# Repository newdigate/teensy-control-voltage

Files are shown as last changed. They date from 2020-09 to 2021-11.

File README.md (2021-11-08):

# teensy control voltage analog computer shield 








**open source [hardware](hardware) ~~and [software](software)~~ for a [teensy 4.1](https://www.pjrc.com/store/teensy40.html "teensy 4.1 board") eurorack control voltage shield** 

extend a [teensy 4.1](https://www.pjrc.com/store/teensy40.html "teensy 4.1 board") with peripherals to interface with eurorack modular equipment. 

 




## specifications
* **microcontrollers:** 
  * 600 Mhz ARM cortex m7 ( [teensy 4.1 board](https://www.pjrc.com/store/teensy41.html "teensy 4.1 board") )
* **display:** ST7735 128x128 16bit-color tft display
* **breakouts:** 
  * microSD card socket, 
  * USB host/device, 
  * midi in/out, 
  * 1 x encoders w/switch
* **panel:** 14HP aluminium panel mounted for eurorack case
* **programability**: 
  * write arduino compatible c/c++ firmware & program using arduino/teensyduino
  * arm gnu toolchain [downloads](https://developer.arm.com/tools-and-software/open-source-software/developer-tools/gnu-toolchain/gnu-rm/downloads)
  * teensy [audio library](https://www.pjrc.com/teensy/gui/)

## MIT open source license
* MIT license unless otherwise specified on a per file basis.

## Open source software stack
* All [schematics](hardware/CIRCUITS.md) and boards are created using [Kicad](http://kicad.org/) 
* All mechanical designs are created using [FreeCAD](https://github.com/FreeCAD/FreeCAD)
* Some images have been rendered using [Blender 2.81](https://www.blender.org/)

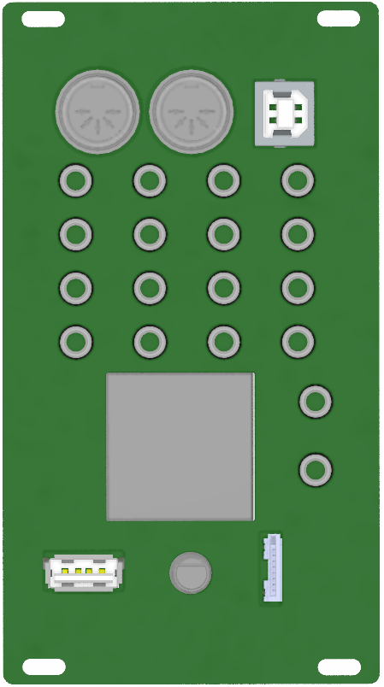
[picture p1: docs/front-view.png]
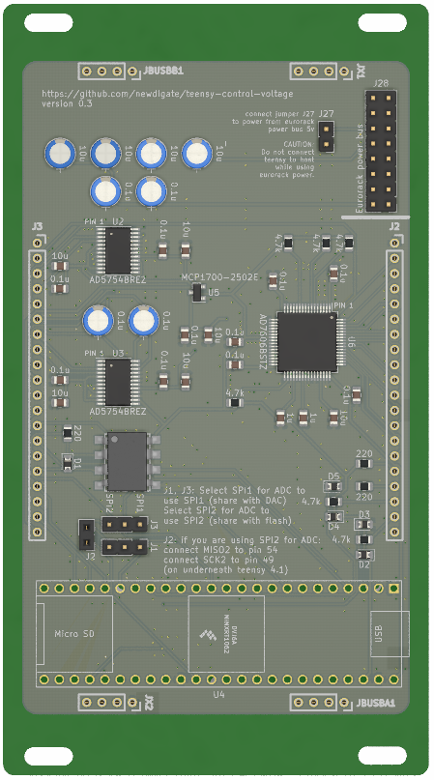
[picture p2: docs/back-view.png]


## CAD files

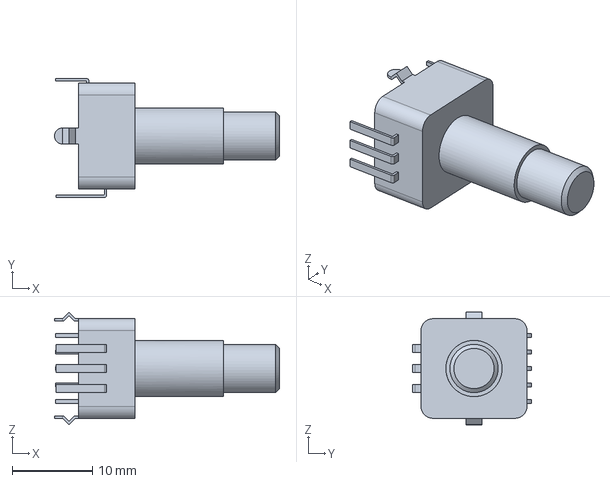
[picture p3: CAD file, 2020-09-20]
hardware/boards/3d/Bourns PEL12T4225S-S1024.step
28.0 x 14.8 x 14.0 mm

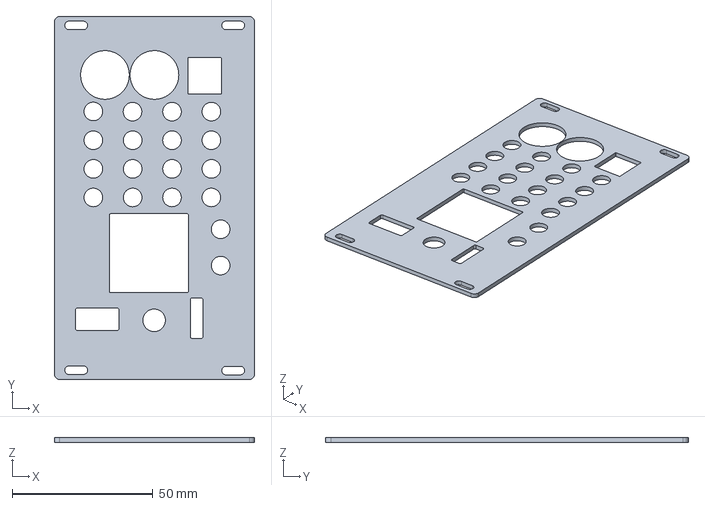
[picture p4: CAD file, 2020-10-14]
hardware/front-panel/front-panel.step
71.1 x 128.9 x 1.60 mm

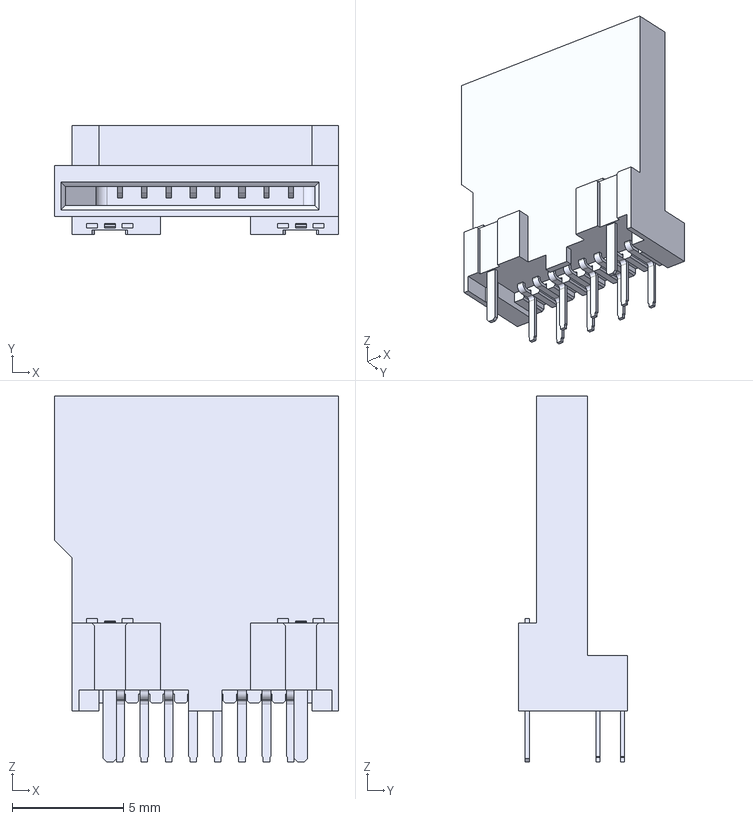
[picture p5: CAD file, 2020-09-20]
hardware/boards/3d/Yamaichi - PJS008U-3000-0.step
12.8 x 4.90 x 16.5 mm

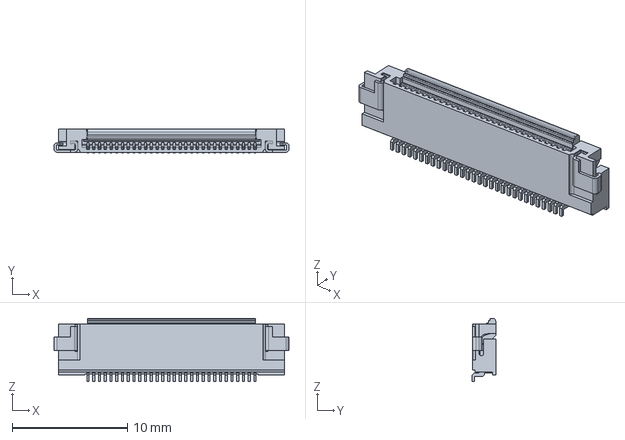
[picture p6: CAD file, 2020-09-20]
hardware/boards/3d/Molex-52892-3033.step
20.4 x 2.04 x 5.50 mm

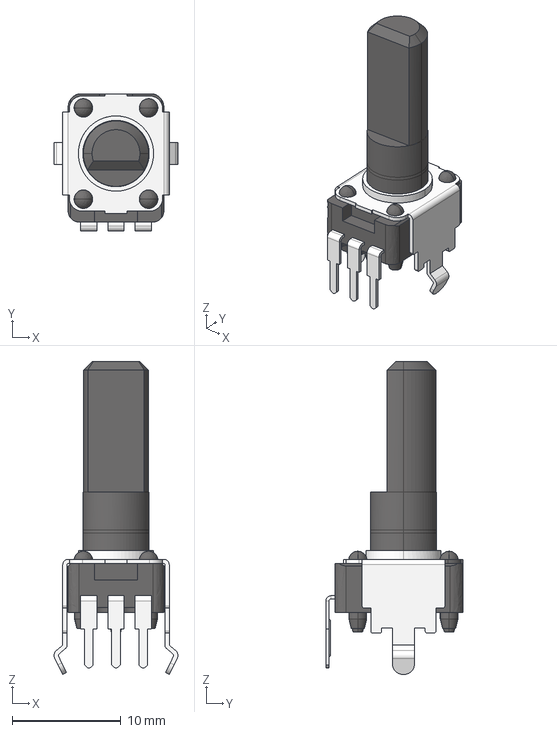
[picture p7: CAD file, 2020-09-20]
hardware/boards/3d/RK09K1130AH1.STEP
11.4 x 12.7 x 28.8 mm

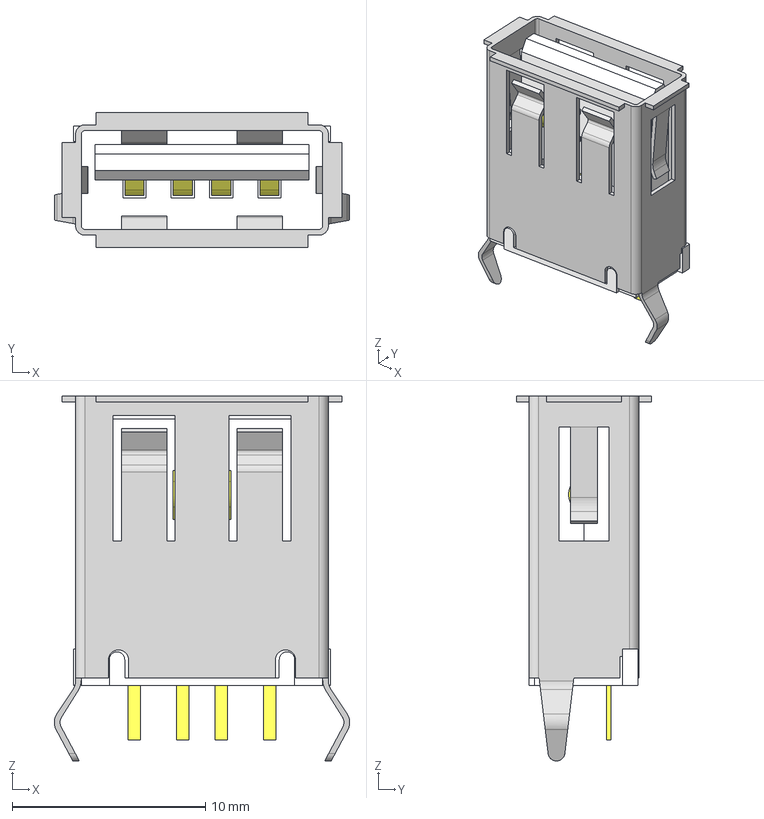
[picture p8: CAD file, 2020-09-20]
hardware/boards/3d/USB-A-S-S-W-VT.stp
15.3 x 7.00 x 18.9 mm
_USB-A-S-VT_S
_USB-A-S-W-VT_B
_USB-A-S-VT_P

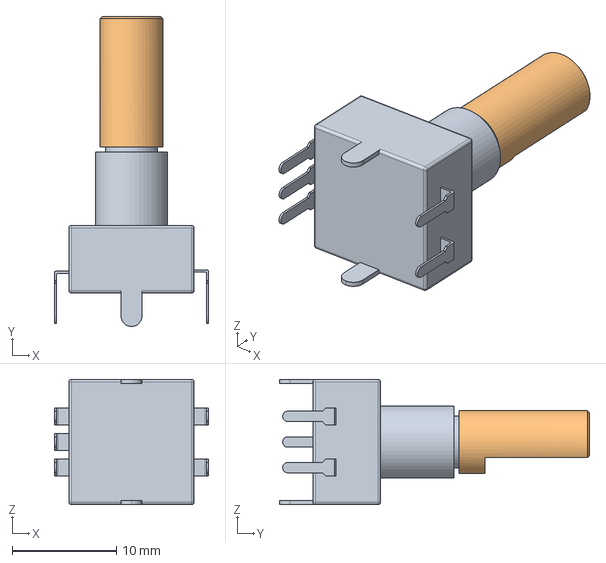
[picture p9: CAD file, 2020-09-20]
hardware/boards/3d/RotaryEncoder_Alps_EC11E-Switch_Vertical_H20mm.step
14.8 x 29.7 x 12.0 mm

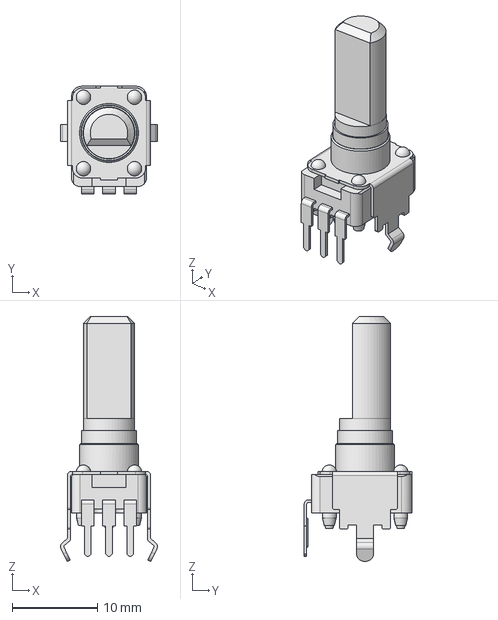
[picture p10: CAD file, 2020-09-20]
hardware/boards/3d/Panasonic_EVU-F2MFL3D14.step
11.4 x 12.7 x 28.8 mm

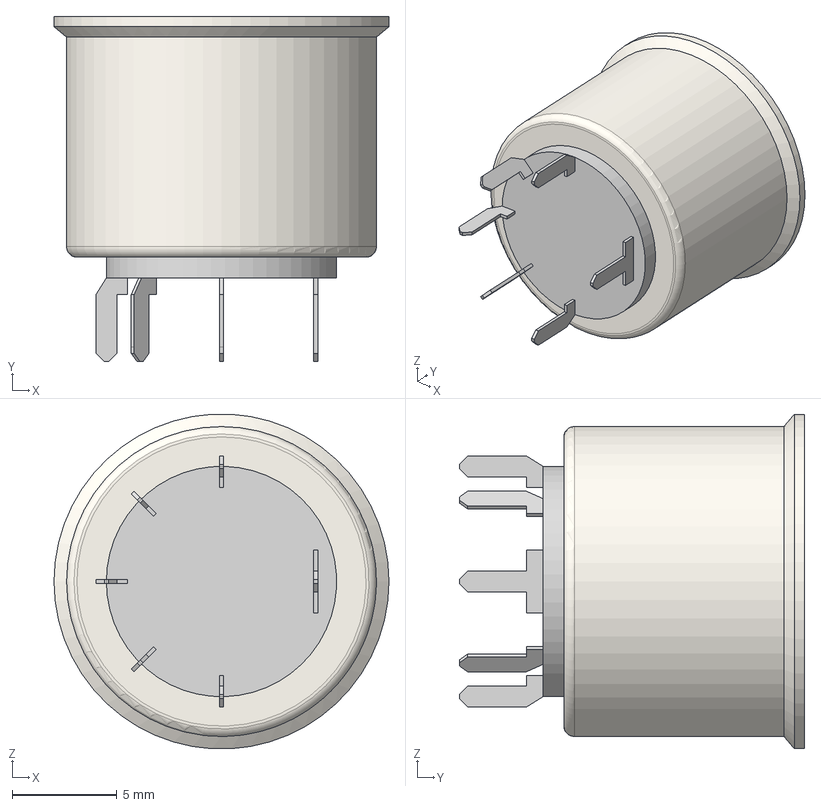
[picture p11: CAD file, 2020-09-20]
hardware/boards/3d/MIDI DIN 5 v7.step
16.0 x 16.5 x 16.0 mm

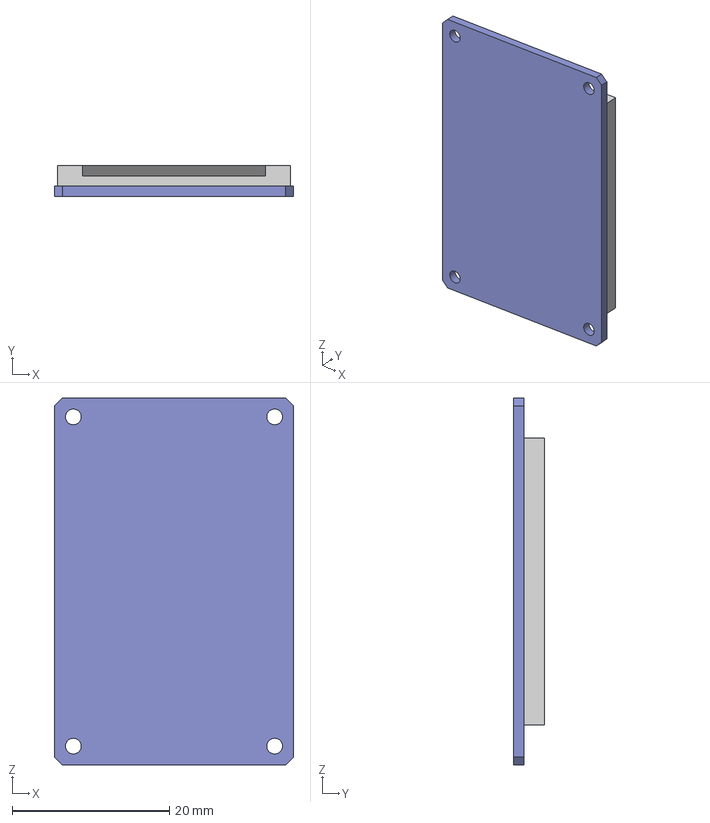
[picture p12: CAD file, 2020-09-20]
hardware/boards/3d/ili7735 v6.step
30.4 x 3.90 x 46.6 mm

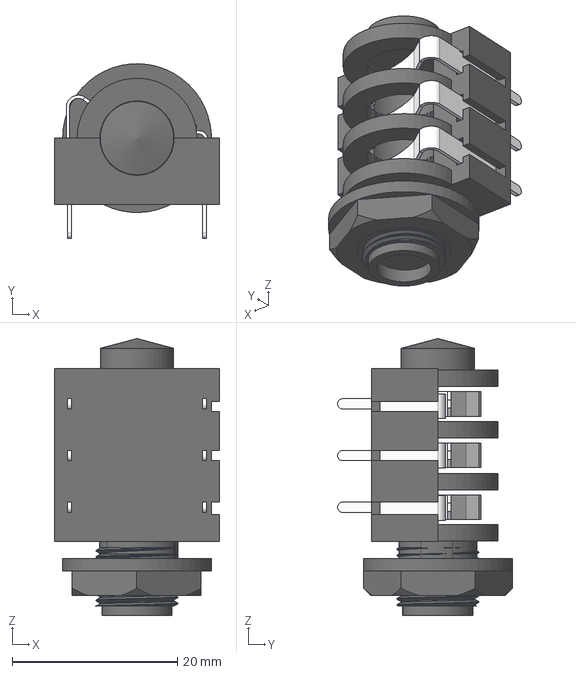
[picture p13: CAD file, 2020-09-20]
hardware/boards/3d/ACJS-PH v28.step
20.0 x 21.1 x 33.5 mm
JackConnector-female-6.35-entrance-threaded
nut

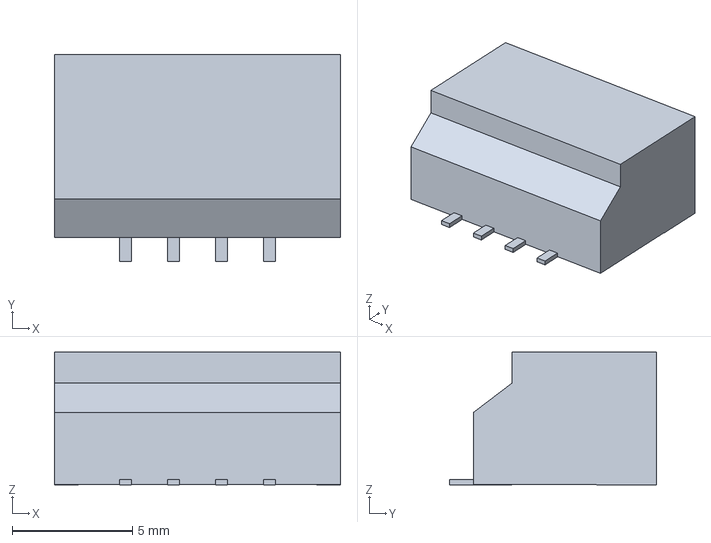
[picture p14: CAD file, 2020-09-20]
hardware/boards/3d/conn_JST_S4B-PH-SM4-TB(LF)(SN).step
11.9 x 8.60 x 5.52 mm

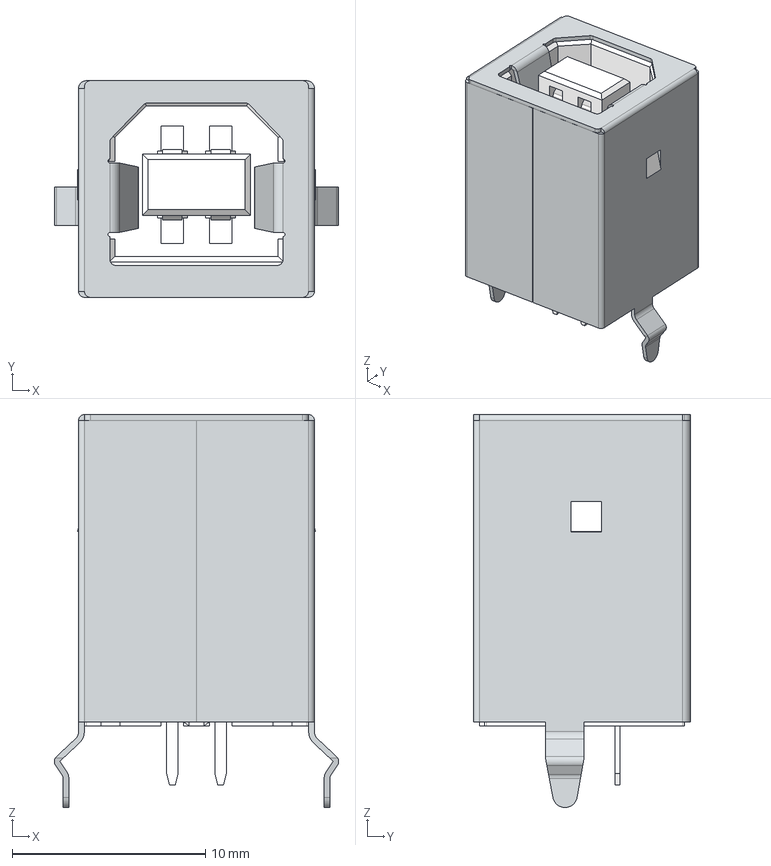
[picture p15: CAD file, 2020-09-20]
hardware/boards/3d/Conn_Wurth Electronics_61400413321.step
14.7 x 11.2 x 20.3 mm

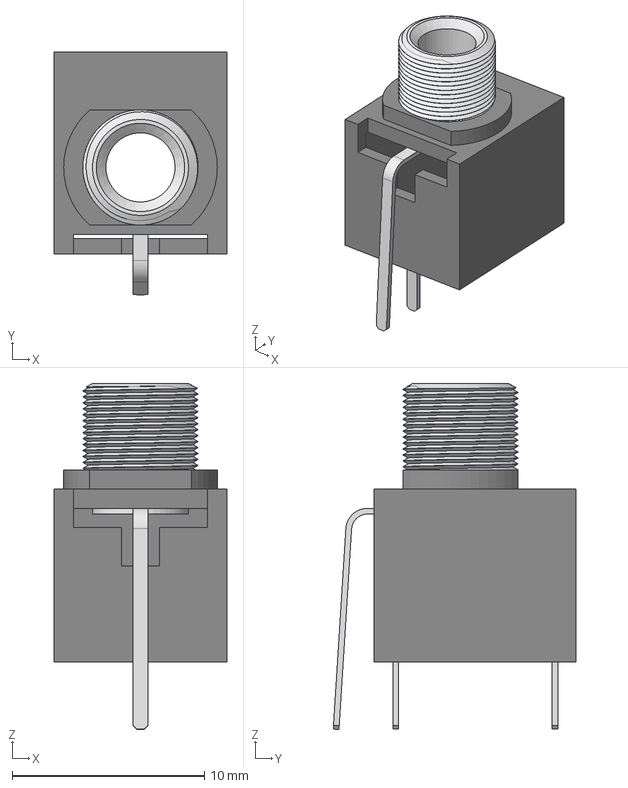
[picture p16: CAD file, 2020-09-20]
hardware/boards/3d/PJ301M-12 Thonkiconn v0.2.stp
9.00 x 12.6 x 18.0 mm

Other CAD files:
hardware/boards/3d/Bourns PEL12T4225S-S1024-white.step
hardware/boards/3d/ACJS-MV35-5.step
hardware/boards/3d/ZX62-AB-5PA.stp
hardware/boards/3d/User Library-8-pin-DIP_GW_HCPL-4200-300E.STEP
hardware/boards/3d/1734592-8.stp
hardware/boards/3d/CS42448-CQZ.step
hardware/boards/3d/HFW8R-1STE1LF.stp

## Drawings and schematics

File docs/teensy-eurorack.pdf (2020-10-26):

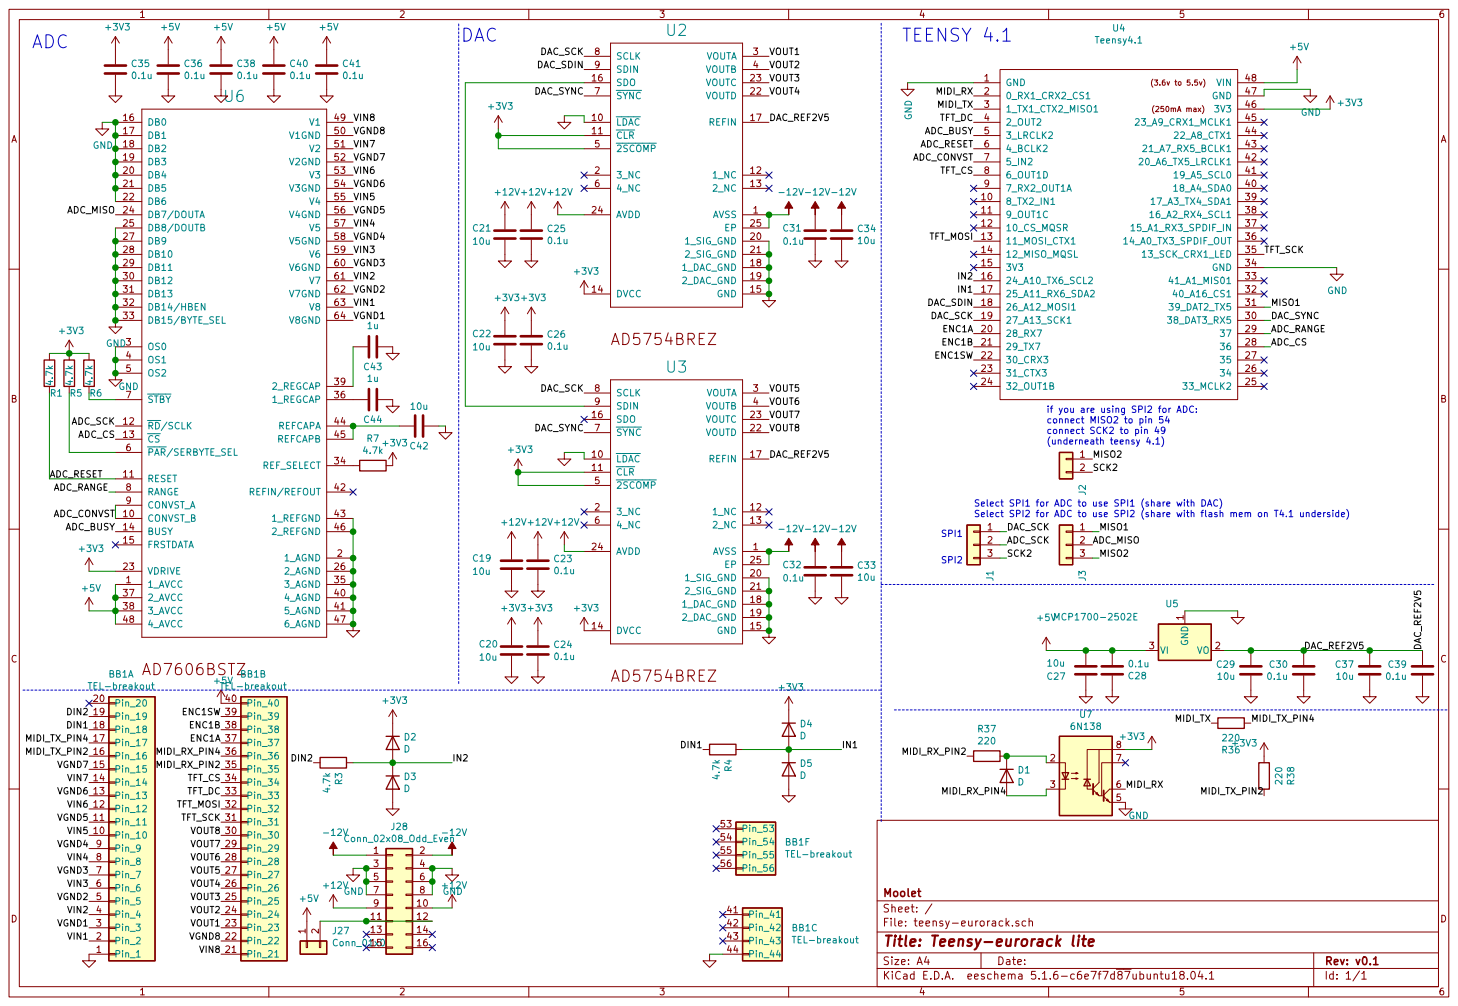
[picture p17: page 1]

if you are using SPI2 for ADC:
connect MISO2 to pin 54
connect SCK2 to pin 49
(underneath teensy 4.1)

Select SPI1 for ADC to use SPI1 (share with DAC)

Select SPI2 for ADC to use SPI2 (share with flash mem on T4.1 underside) SPI1 SPI2

File: teensy-eurorack.sch Sheet: / Moolet

Id: 1/1 Title: Teensy-eurorack lite

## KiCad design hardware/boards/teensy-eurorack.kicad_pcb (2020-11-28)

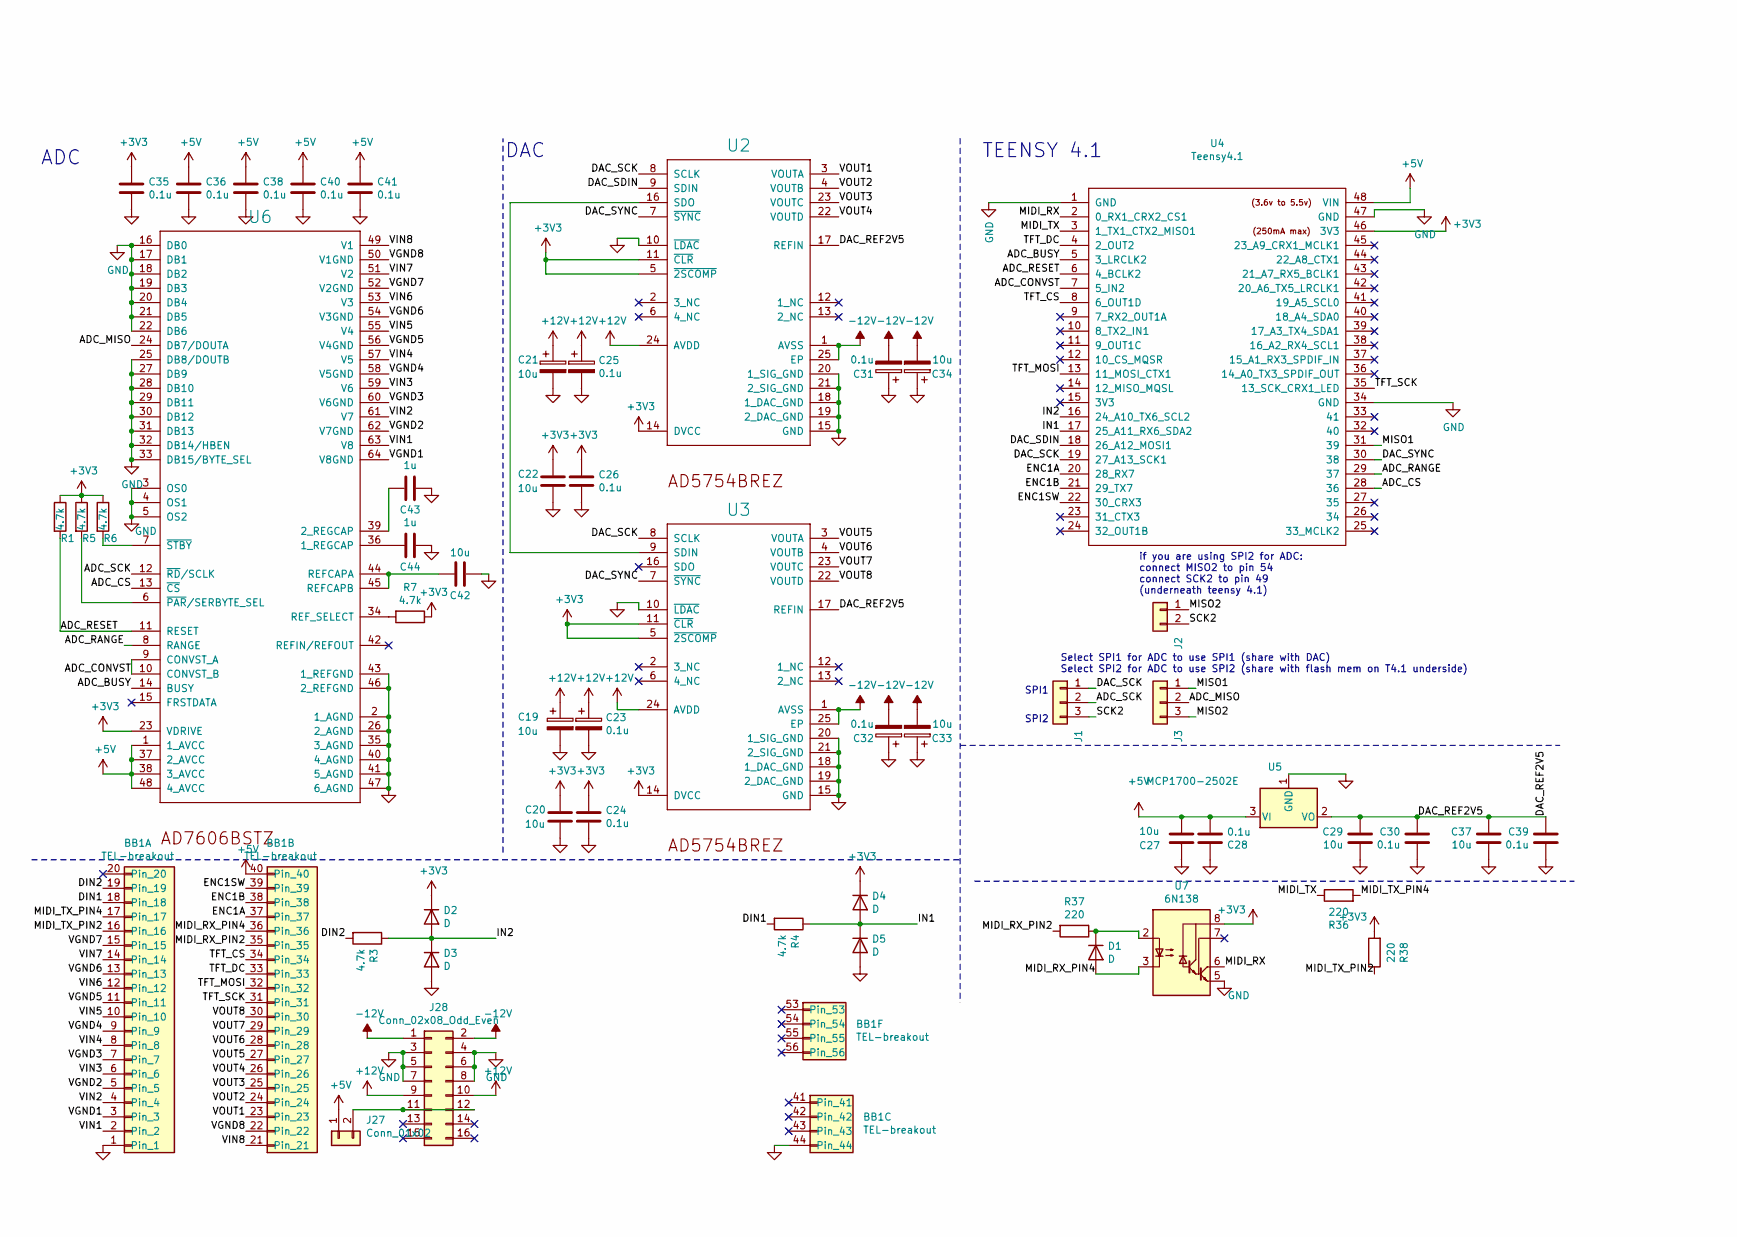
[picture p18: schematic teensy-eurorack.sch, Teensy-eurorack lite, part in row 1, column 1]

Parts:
BB1: TEL-breakout; TElite-breakout-board
C19, C21, C33, C34: 10u; CP_Radial_D5.0mm_P2.00mm
C20, C22, C27, C29, C37, C42: 10u; C_0805_2012Metric
C23, C25, C31, C32: 0.1u; CP_Radial_D5.0mm_P2.00mm
C24, C26, C28, C30, C35, C36, C38, C39, C40, C41: 0.1u; C_0805_2012Metric
C43, C44: 1u; C_0805_2012Metric
D1, D2, D3, D4, D5: D; D_0805_2012Metric
J1, J3: Conn_01x03; Pin_Header_Straight_1x03_Pitch2.54mm
J2: Conn_01x02; Pin_Header_Straight_1x02_Pitch2.54mm
J27: Conn_01x02; PinHeader_1x02_P2.54mm_Vertical
J28: Conn_02x08_Odd_Even; PinHeader_2x08_P2.54mm_Vertical
R1, R3, R4, R5, R6, R7: 4.7k; R_0805_2012Metric
R36, R37, R38: 220; R_0805_2012Metric
U2, U3: AD5754BREZ; HTSSOP-24-1EP_4.4x7.8mm_P0.65mm_EP3.2x5mm
U4: Teensy4.1; Teensy41_tht
U5: MCP1700-2502E; SOT-23
U6: AD7606BSTZ; LQFP-64_10x10mm_P0.5mm
U7: 6N138; 6N138S

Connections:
+3V3: C20.1, C22.1, C24.1, C26.1, C35.1, D2.1 (K), D4.1 (K), R1.1, R5.1, R6.1, R7.1, R38.2, U2.5 (~2SCOMP~), U2.11 (~CLR~), U2.14 (DVCC), U3.5 (~2SCOMP~), U3.11 (~CLR~), U3.14 (DVCC), U4.46 (3V3), U6.23 (VDRIVE), U7.8 (VCC)
+5V: BB1.40, C27.2, C28.2, C36.1, C38.1, C40.1, C41.1, J27.1, U4.48 (VIN), U5.3 (VI), U6.1 (1_AVCC), U6.37 (2_AVCC), U6.38 (3_AVCC), U6.48 (4_AVCC)
+12V: C19.1, C21.1, C23.1, C25.1, J28.9, J28.10, U2.24 (AVDD), U3.24 (AVDD)
-12V: C31.2, C32.2, C33.2, C34.2, J28.1, J28.2, U2.1 (AVSS), U2.25 (EP), U3.1 (AVSS), U3.25 (EP)
/ADC_BUSY: U4.5 (3_LRCLK2), U6.14 (BUSY)
/ADC_CONVST: U4.7 (5_IN2), U6.9 (CONVST_A), U6.10 (CONVST_B)
/ADC_CS: U4.28 (36), U6.13 (~CS~)
/ADC_MISO: J3.2, U6.24 (DB7/DOUTA)
/ADC_RANGE: U4.29 (37), U6.8 (RANGE)
/ADC_RESET: R1.2, U4.6 (4_BCLK2), U6.11 (RESET)
/ADC_SCK: J1.2, U6.12 (~RD~/SCLK)
/DAC_REF2V5: C29.1, C30.1, C37.1, C39.1, U2.17 (REFIN), U3.17 (REFIN), U5.2 (VO)
/DAC_SCK: J1.1, U2.8 (SCLK), U3.8 (SCLK), U4.19 (27_A13_SCK1)
/DAC_SDIN: U2.9 (SDIN), U4.18 (26_A12_MOSI1)
/DAC_SYNC: U2.7 (~SYNC~), U3.7 (~SYNC~), U4.30 (38)
/DIN1: BB1.18, R4.2
/DIN2: BB1.19, R3.2
/ENC1A: BB1.37, U4.20 (28_RX7)
/ENC1B: BB1.38, U4.21 (29_TX7)
/ENC1SW: BB1.39, U4.22 (30_CRX3)
/IN1: D4.2 (A), D5.1 (K), R4.1, U4.17 (25_A11_RX6_SDA2)
/IN2: D2.2 (A), D3.1 (K), R3.1, U4.16 (24_A10_TX6_SCL2)
/MIDI_RX: U4.2 (0_RX1_CRX2_CS1), U7.6 (VO2)
/MIDI_RX_PIN2: BB1.35, R37.2
/MIDI_RX_PIN4: BB1.36, D1.2 (A), U7.3 (C2)
/MIDI_TX: R36.1, U4.3 (1_TX1_CTX2_MISO1)
/MIDI_TX_PIN2: BB1.16, R38.1
/MIDI_TX_PIN4: BB1.17, R36.2
/MISO1: J3.1, U4.31 (39)
/MISO2: J2.1, J3.3
/SCK2: J1.3, J2.2
/TFT_CS: BB1.34, U4.8 (6_OUT1D)
/TFT_DC: BB1.33, U4.4 (2_OUT2)
/TFT_MOSI: BB1.32, U4.13 (11_MOSI_CTX1)
/TFT_SCK: BB1.31, U4.35 (13_SCK_CRX1_LED)
/VGND1: BB1.3, U6.64 (V8GND)
/VGND2: BB1.5, U6.62 (V7GND)
/VGND3: BB1.7, U6.60 (V6GND)
/VGND4: BB1.9, U6.58 (V5GND)
/VGND5: BB1.11, U6.56 (V4GND)
/VGND6: BB1.13, U6.54 (V3GND)
/VGND7: BB1.15, U6.52 (V2GND)
/VGND8: BB1.22, U6.50 (V1GND)
/VIN1: BB1.2, U6.63 (V8)
/VIN2: BB1.4, U6.61 (V7)
/VIN3: BB1.6, U6.59 (V6)
/VIN4: BB1.8, U6.57 (V5)
/VIN5: BB1.10, U6.55 (V4)
/VIN6: BB1.12, U6.53 (V3)
/VIN7: BB1.14, U6.51 (V2)
/VIN8: BB1.21, U6.49 (V1)
/VOUT1: BB1.23, U2.3 (VOUTA)
/VOUT2: BB1.24, U2.4 (VOUTB)
/VOUT3: BB1.25, U2.23 (VOUTC)
/VOUT4: BB1.26, U2.22 (VOUTD)
/VOUT5: BB1.27, U3.3 (VOUTA)
/VOUT6: BB1.28, U3.4 (VOUTB)
/VOUT7: BB1.29, U3.23 (VOUTC)
/VOUT8: BB1.30, U3.22 (VOUTD)
GND: BB1.1, BB1.44, C19.2, C20.2, C21.2, C22.2, C23.2, C24.2, C25.2, C26.2, C27.1, C28.1, C29.2, C30.2, C31.1, C32.1, C33.1, C34.1, C35.2, C36.2, C37.2, C38.2, C39.2, C40.2, C41.2, C42.1, C43.1, C44.1, D3.2 (A), D5.2 (A), J28.3, J28.4, J28.5, J28.6, J28.7, J28.8, U2.10 (~LDAC~), U2.15 (GND), U2.18 (1_DAC_GND), U2.19 (2_DAC_GND), U2.20 (1_SIG_GND), U2.21 (2_SIG_GND), U3.10 (~LDAC~), U3.15 (GND), U3.18 (1_DAC_GND), U3.19 (2_DAC_GND), U3.20 (1_SIG_GND), U3.21 (2_SIG_GND), U4.1 (GND), U4.34 (GND), U4.47 (GND), U5.1 (GND), U6.2 (1_AGND), U6.3 (OS0), U6.4 (OS1), U6.5 (OS2), U6.16 (DB0), U6.17 (DB1), U6.18 (DB2), U6.19 (DB3), U6.20 (DB4), U6.21 (DB5), U6.22 (DB6), U6.25 (DB8/DOUTB), U6.26 (2_AGND), U6.27 (DB9), U6.28 (DB10), U6.29 (DB11), U6.30 (DB12), U6.31 (DB13), U6.32 (DB14/HBEN), U6.33 (DB15/BYTE_SEL), U6.35 (3_AGND), U6.40 (4_AGND), U6.41 (5_AGND), U6.43 (1_REFGND), U6.46 (2_REFGND), U6.47 (6_AGND), U7.5 (GND)
unnamed: C42.2, U6.44 (REFCAPA), U6.45 (REFCAPB)
unnamed: C43.2, U6.39 (2_REGCAP)
unnamed: C44.2, U6.36 (1_REGCAP)
unnamed: D1.1 (K), R37.1, U7.2 (C1)
unnamed: J27.2, J28.11, J28.12
unnamed: R5.2, U6.6 (~PAR~/SERBYTE_SEL)
unnamed: R6.2, U6.7 (~STBY~)
unnamed: R7.2, U6.34 (REF_SELECT)
unnamed: U2.16 (SDO), U3.9 (SDIN)

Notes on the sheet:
TEENSY 4.1
ADC
DAC
if you are using SPI2 for ADC: connect MISO2 to pin 54 connect SCK2 to pin 49 (underneath teensy 4.1)
Select SPI1 for ADC to use SPI1 (share with DAC) Select SPI2 for ADC to use SPI2 (share with flash mem on T4.1 underside)
SPI1
SPI2

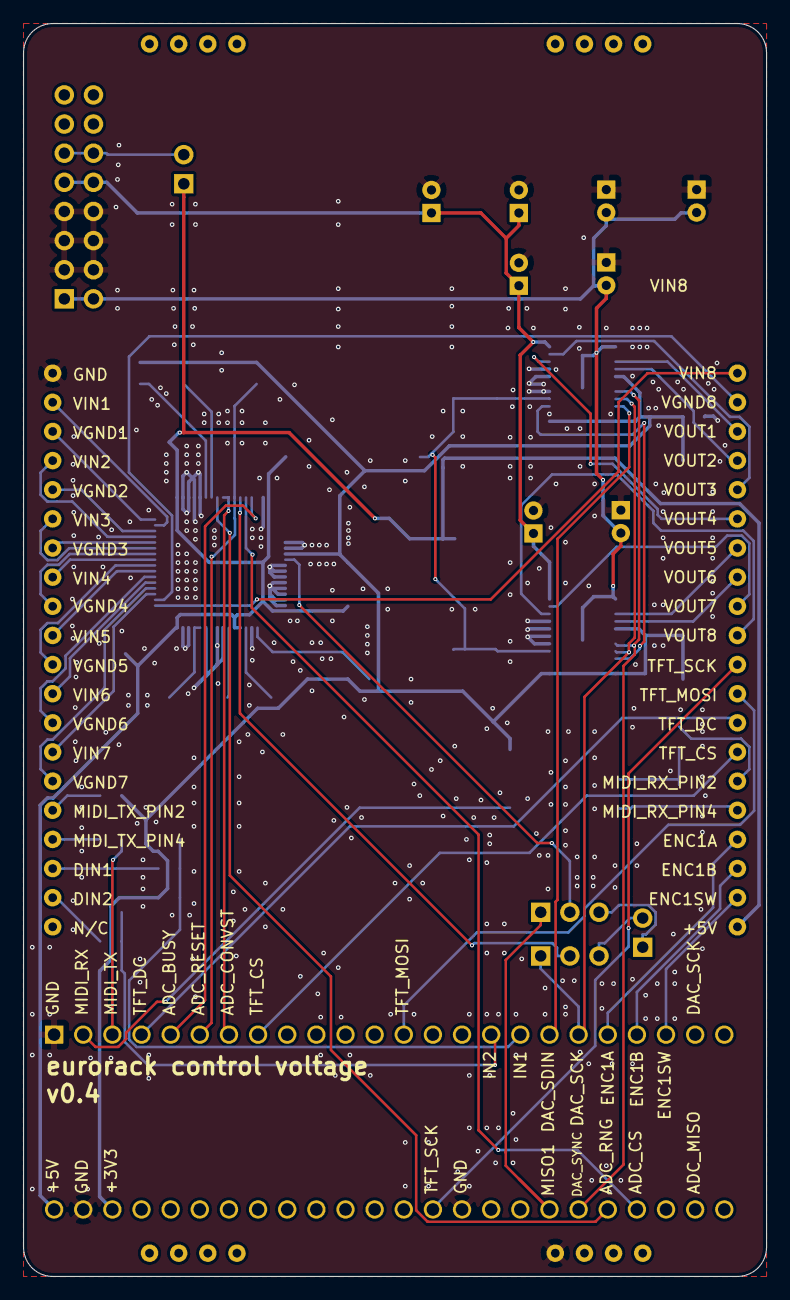
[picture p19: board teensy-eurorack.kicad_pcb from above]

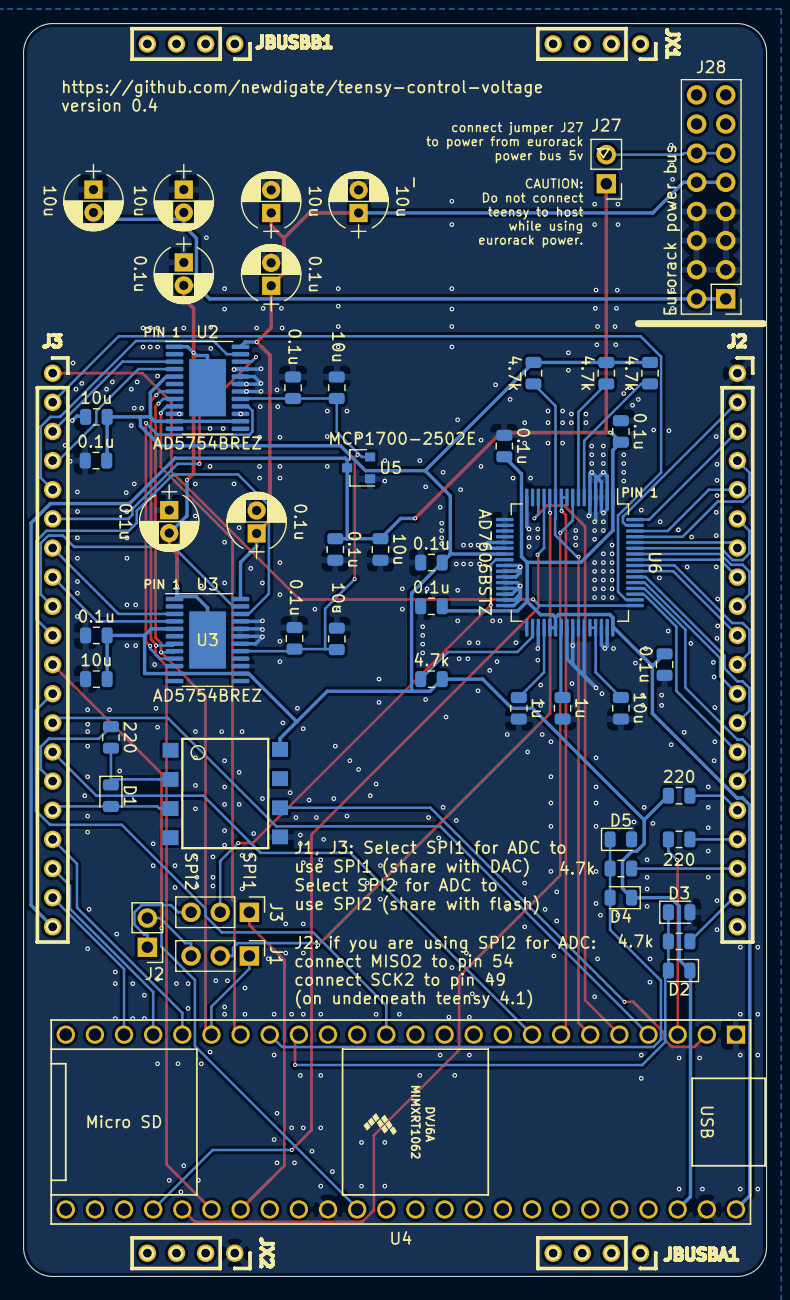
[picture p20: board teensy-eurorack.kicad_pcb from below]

Board: 2 copper layers, 64.8 x 109.2 mm, 52 parts (51 on the bottom side), 69 nets.

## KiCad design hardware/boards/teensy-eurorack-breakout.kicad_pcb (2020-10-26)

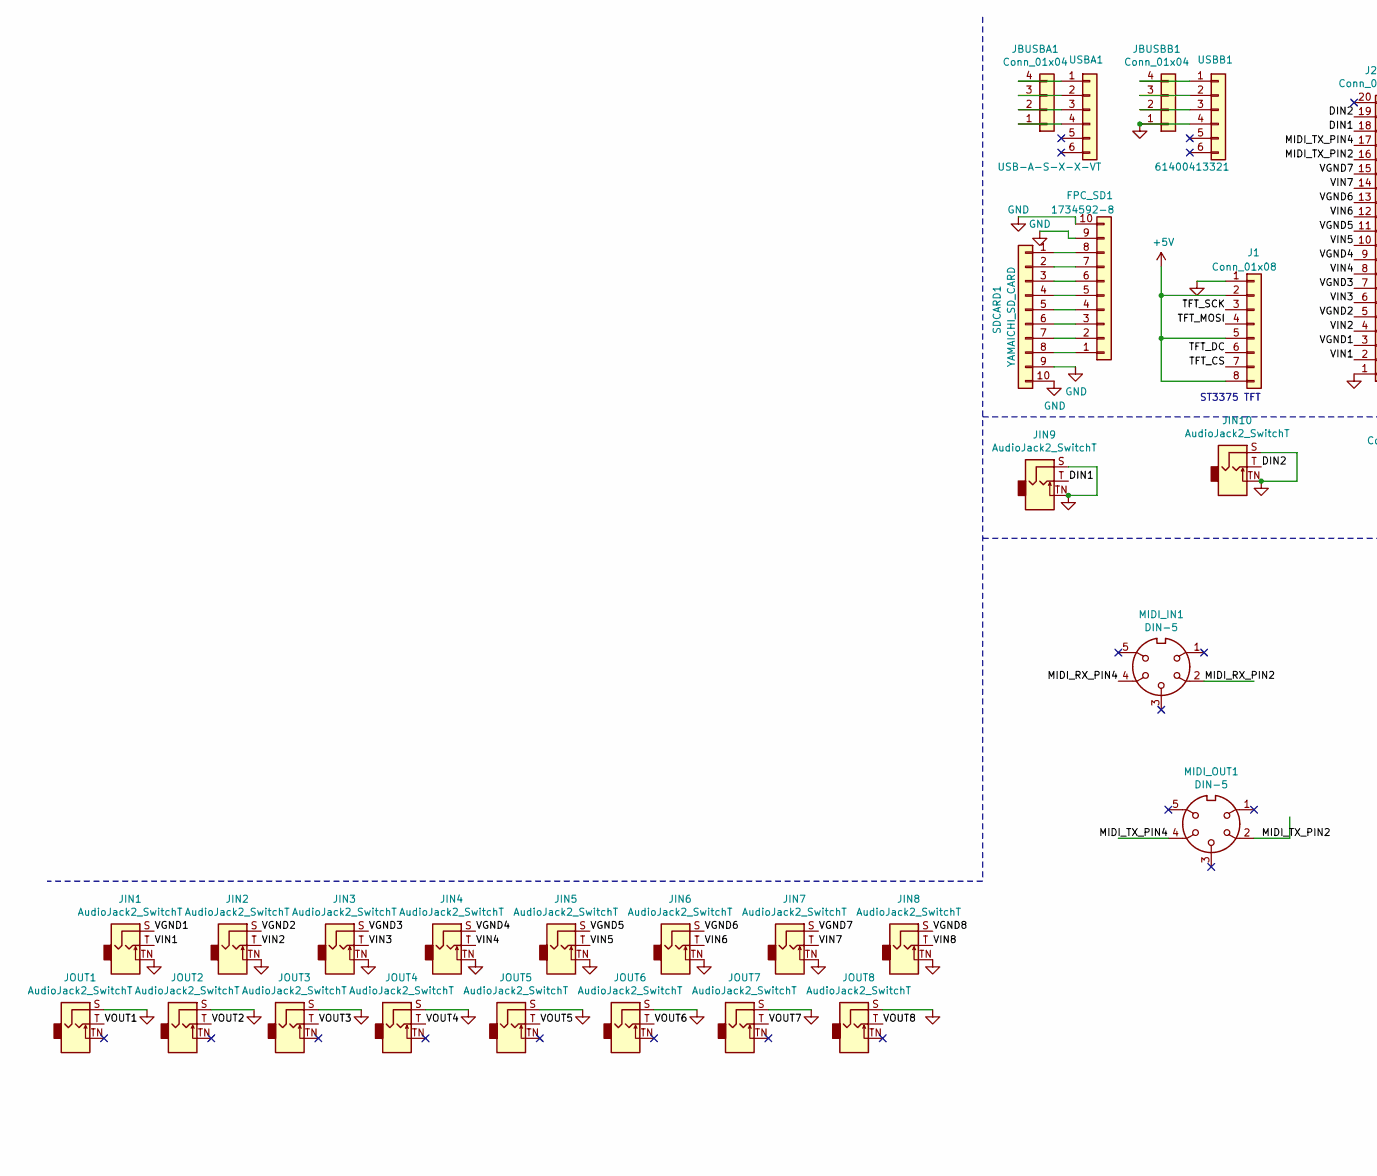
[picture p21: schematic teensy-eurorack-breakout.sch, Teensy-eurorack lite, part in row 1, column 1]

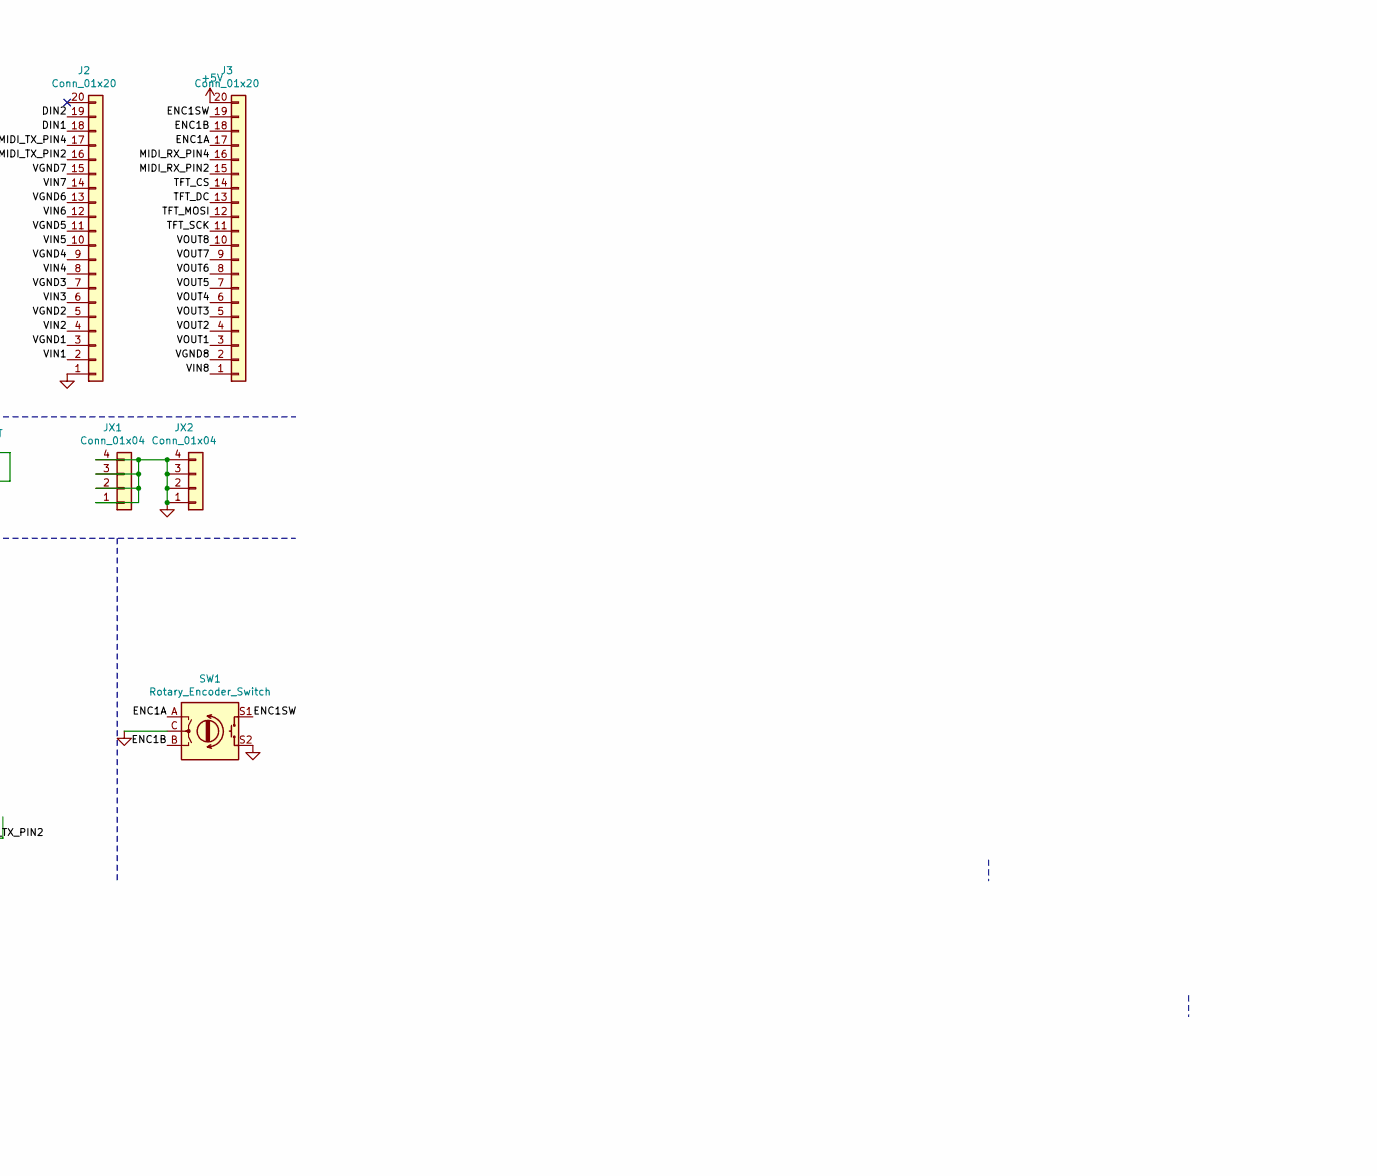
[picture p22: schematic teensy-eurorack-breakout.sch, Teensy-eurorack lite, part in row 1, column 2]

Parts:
FPC_SD1: 1734592-8; HFW8R-1STE1LF
J1: Conn_01x08; ST7735
J2, J3: Conn_01x20; PinSocket_1x20_P2.54mm_Vertical
JBUSBA1: Conn_01x04; PinSocket_1x04_P2.54mm_Vertical
JBUSBB1: Conn_01x04; PinSocket_1x04_P2.54mm_Vertical
JIN1, JIN2, JIN3, JIN4, JIN5, JIN6, JIN7, JIN8, JIN9, JIN10: AudioJack2_SwitchT; WQP-PJ301M-12_JACK
JOUT1, JOUT2, JOUT3, JOUT4, JOUT5, JOUT6, JOUT7, JOUT8: AudioJack2_SwitchT; WQP-PJ301M-12_JACK
JX1, JX2: Conn_01x04; PinSocket_1x04_P2.54mm_Vertical
MIDI_IN1: DIN-5; OG-MIDI_SD-50BV
MIDI_OUT1: DIN-5; OG-MIDI_SD-50BV
SDCARD1: YAMAICHI_SD_CARD; YAMAICHI_MICROSD_VERTICAL
SW1: Rotary_Encoder_Switch; RotaryEncoder_Alps_EC12E-Switch_Vertical_H20mm_CircularMoun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
USBA1: USB-A-S-X-X-VT
USBB1: 61400413321; WURTH_ELECTRONICS_61400413321_0

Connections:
+5V: J1.2, J1.5, J1.8, J3.20
/DIN1: J2.18, JIN9.T
/DIN2: J2.19, JIN10.T
/ENC1A: J3.17, SW1.A
/ENC1B: J3.18, SW1.B
/ENC1SW: J3.19, SW1.S1
/MIDI_RX_PIN2: J3.15, MIDI_IN1.2
/MIDI_RX_PIN4: J3.16, MIDI_IN1.4
/MIDI_TX_PIN2: J2.16, MIDI_OUT1.2
/MIDI_TX_PIN4: J2.17, MIDI_OUT1.4
/TFT_CS: J1.7, J3.14
/TFT_DC: J1.6, J3.13
/TFT_MOSI: J1.4, J3.12
/TFT_SCK: J1.3, J3.11
/VGND1: J2.3, JIN1.S
/VGND2: J2.5, JIN2.S
/VGND3: J2.7, JIN3.S
/VGND4: J2.9, JIN4.S
/VGND5: J2.11, JIN5.S
/VGND6: J2.13, JIN6.S
/VGND7: J2.15, JIN7.S
/VGND8: J3.2, JIN8.S
/VIN1: J2.2, JIN1.T
/VIN2: J2.4, JIN2.T
/VIN3: J2.6, JIN3.T
/VIN4: J2.8, JIN4.T
/VIN5: J2.10, JIN5.T
/VIN6: J2.12, JIN6.T
/VIN7: J2.14, JIN7.T
/VIN8: J3.1, JIN8.T
/VOUT1: J3.3, JOUT1.T
/VOUT2: J3.4, JOUT2.T
/VOUT3: J3.5, JOUT3.T
/VOUT4: J3.6, JOUT4.T
/VOUT5: J3.7, JOUT5.T
/VOUT6: J3.8, JOUT6.T
/VOUT7: J3.9, JOUT7.T
/VOUT8: J3.10, JOUT8.T
GND: FPC_SD1.9, FPC_SD1.10, J1.1, J2.1, JBUSBB1.1, JIN1.TN, JIN2.TN, JIN3.TN, JIN4.TN, JIN5.TN, JIN6.TN, JIN7.TN, JIN8.TN, JIN9.S, JIN9.TN, JIN10.S, JIN10.TN, JOUT1.S, JOUT2.S, JOUT3.S, JOUT4.S, JOUT5.S, JOUT6.S, JOUT7.S, JOUT8.S, JX1.1, JX1.2, JX1.3, JX1.4, JX2.1, JX2.2, JX2.3, JX2.4, SDCARD1.9, SDCARD1.10, SW1.C, SW1.S2, USBB1.4
unnamed: FPC_SD1.1, SDCARD1.8
unnamed: FPC_SD1.2, SDCARD1.7
unnamed: FPC_SD1.3, SDCARD1.6
unnamed: FPC_SD1.4, SDCARD1.5
unnamed: FPC_SD1.5, SDCARD1.4
unnamed: FPC_SD1.6, SDCARD1.3
unnamed: FPC_SD1.7, SDCARD1.2
unnamed: FPC_SD1.8, SDCARD1.1
unnamed: JBUSBA1.1, USBA1.4
unnamed: JBUSBA1.2, USBA1.3
unnamed: JBUSBA1.3, USBA1.2
unnamed: JBUSBA1.4, USBA1.1
unnamed: JBUSBB1.2, USBB1.3
unnamed: JBUSBB1.3, USBB1.2
unnamed: JBUSBB1.4, USBB1.1

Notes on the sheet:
ST3375 TFT

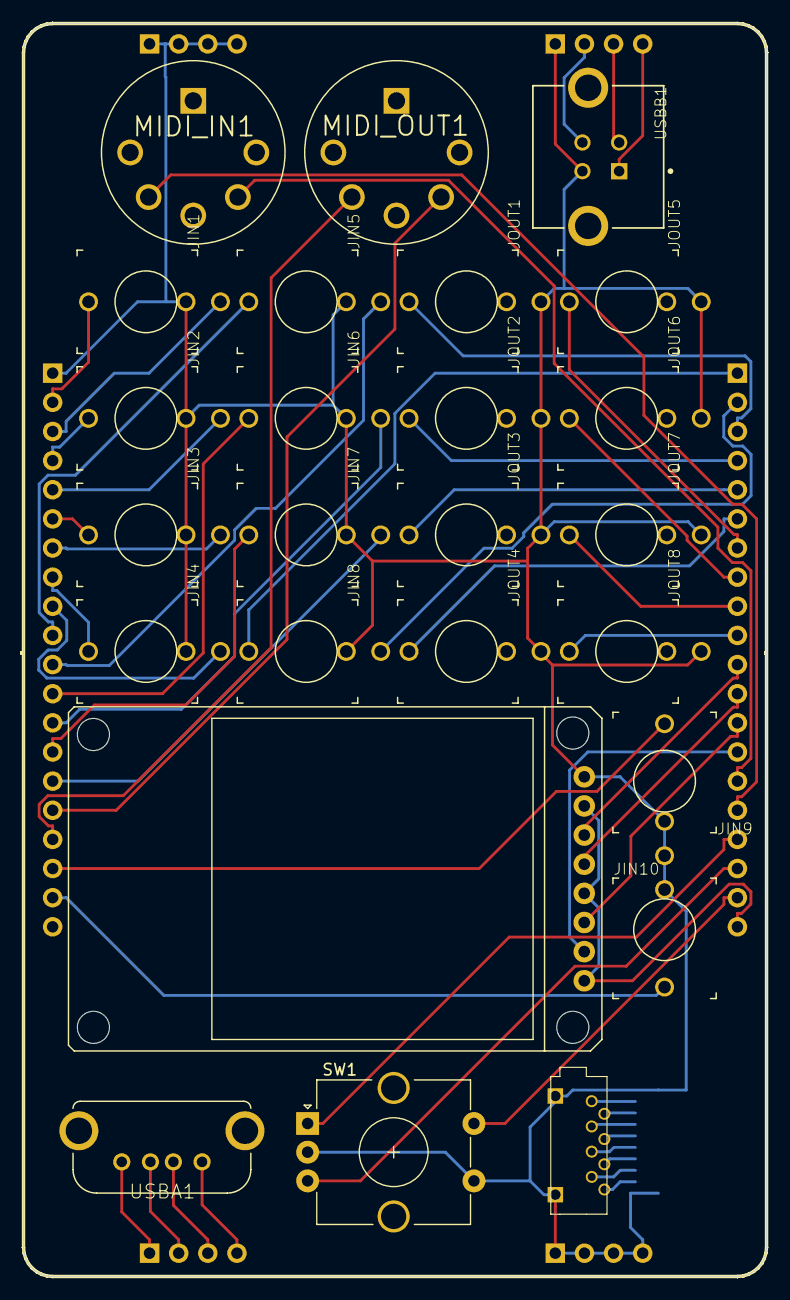
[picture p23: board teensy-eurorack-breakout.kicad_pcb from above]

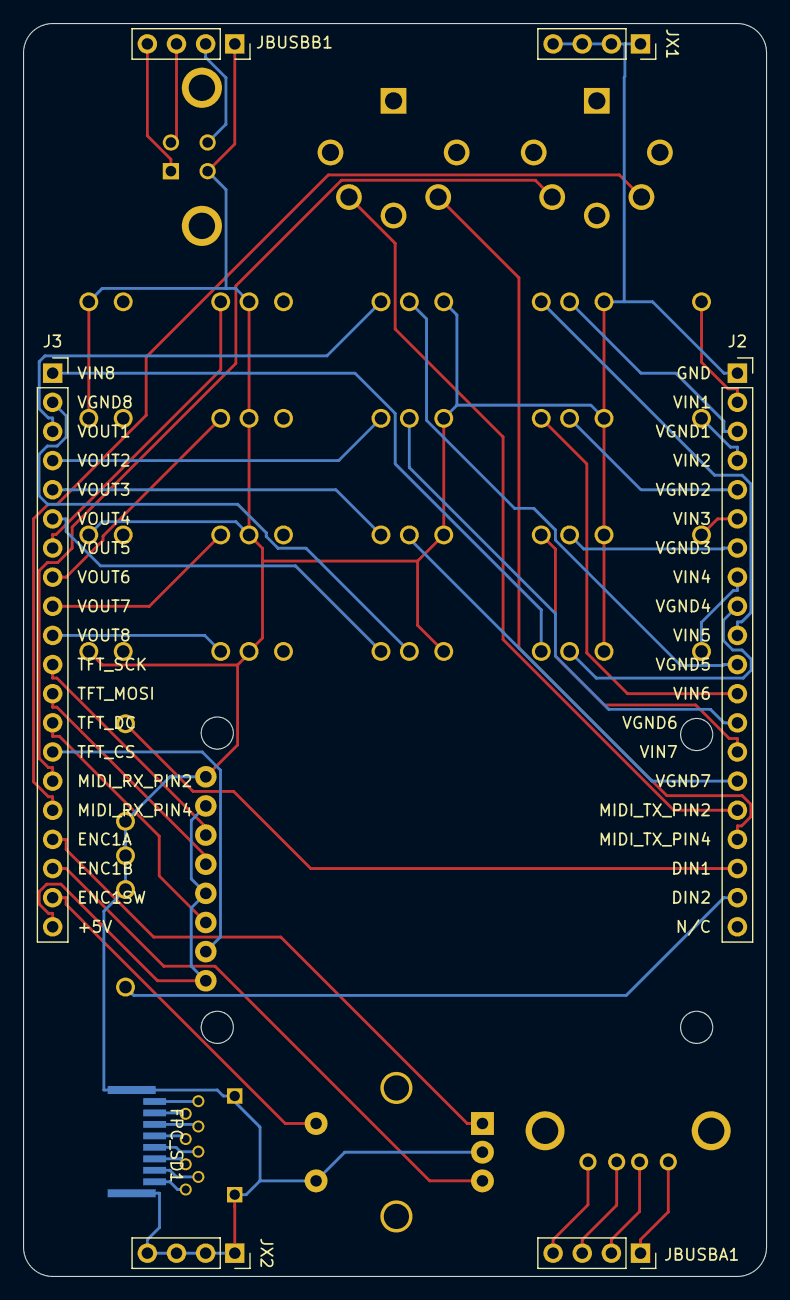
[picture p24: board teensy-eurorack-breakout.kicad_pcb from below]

Board: 2 copper layers, 64.8 x 109.2 mm, 32 parts (7 on the bottom side), 54 nets.

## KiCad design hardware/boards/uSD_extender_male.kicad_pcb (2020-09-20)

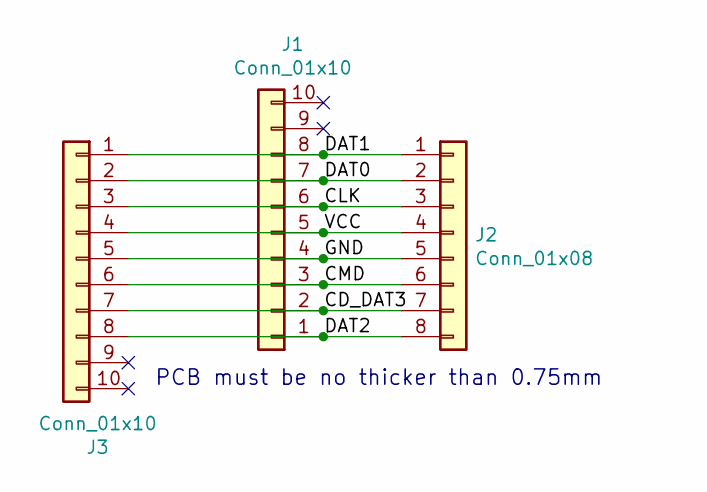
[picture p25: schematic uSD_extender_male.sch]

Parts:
J1, J3: Conn_01x10; HFW8R-1STE1LF
J2: Conn_01x08; MICRO-SDCARD

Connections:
/CD_DAT3: J1.2, J2.7, J3.7
/CLK: J1.6, J2.3, J3.3
/CMD: J1.3, J2.6, J3.6
/DAT0: J1.7, J2.2, J3.2
/DAT1: J1.8, J2.1, J3.1
/DAT2: J1.1, J2.8, J3.8
/GND: J1.4, J2.5, J3.5
/VCC: J1.5, J2.4, J3.4

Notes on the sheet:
PCB must be no thicker than 0.75mm

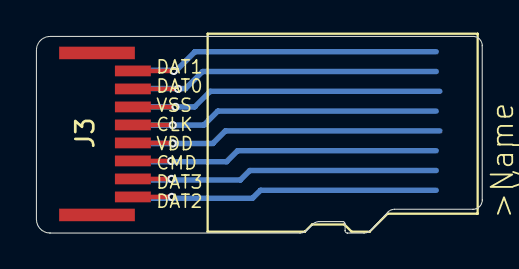
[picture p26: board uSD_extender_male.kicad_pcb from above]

Board: 2 copper layers, 24.8 x 10.9 mm, 3 parts (0 on the bottom side), 8 nets.

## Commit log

2020-09-23 schematic: fix ad7606 pin 8 (range select) from tied to gnd via res, to tied to 3v3 via resistor
    [front-panel.kicad_pcb, teensy-eurorack.sch]
2020-09-23 schematic: hookup ADC_RESET via pullup and ENC1A, ENC1B, ENC1SW
    [teensy-eurorack.sch]
2020-09-23 schematic: move IN1 IN2 from pins 38,39 to 24,25; moved some text / reference designators
    [teensy-eurorack.sch]
2020-09-23 image: mainboard circuit updated
2020-09-23 pull changes from schematic, reroute as double layer board
    [teensy-eurorack.kicad_pcb]
2020-09-23 add gerbers for front-panel
2020-10-04 add interactive BOM for mainboard and breakout
2020-10-13 symbol: corrected pins on teensy 4.1
2020-10-13 updated schematic with jumpers to configure ADC to use either SPI1 or SPI2
    [teensy-eurorack.sch]
2020-10-13 correct footprint to pin headers for jumpers
    [teensy-eurorack.sch]
2020-10-14 rerouted pcb
    [teensy-eurorack.kicad_pcb, teensy-eurorack.sch]
2020-10-14 3d model
    [front-panel.step]
2020-10-14 updated to reference step files
    [teensy-eurorack-breakout.kicad_pcb, teensy-eurorack.kicad_pcb]
2020-10-14 update gerbers
2020-10-14 silkscreen corrections
    [teensy-eurorack.kicad_pcb]
2020-10-26 MISO corrected from pin 41 to pin 39, teensy symbol corrections
    [teensy-eurorack.sch]
2020-10-26 corrections applied to pcb, miso to pin 39
    [teensy-eurorack.kicad_pcb]
2020-10-26 silkscreen corrections and updated to version 0.4
    [teensy-eurorack.kicad_pcb]
2020-11-28 schematic: change dac bypass to polarized cap and change polarity
    [teensy-eurorack.sch]
2020-11-28 pcb: correction to polarity of bypass caps
    [teensy-eurorack.kicad_pcb]
2021-11-08 Update README.md
    https://forum.kicad.info/t/warning-avoid-all-links-to-kicad-pcb-org-use-kicad-org/31521
